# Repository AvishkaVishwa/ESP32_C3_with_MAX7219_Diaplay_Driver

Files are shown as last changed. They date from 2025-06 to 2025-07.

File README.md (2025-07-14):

# ⏰ ESP32‑Powered Smart Clock

> Elegant Wi‑Fi digital clock with MAX7219 4‑digit display, buzzer alarm, and full web control. 

>This project is a Wi-Fi-enabled digital clock built around an ESP32 module that drives a four-digit MAX7219 7-segment display to show real-time hours, minutes, and seconds. A responsive web interface served by the microcontroller lets you set the time, alarms, countdowns, timezone, and home-network credentials, while a buzzer and physical button provide audible alerts and quick dismissal. Running in dual AP/STA mode, the clock creates its own setup hotspot, reconnects to your home Wi-Fi for hourly SNTP synchronization, and stores all settings in NVS for stand-alone, always-accurate operation.
>I did this project to Improve my skills and knowledge in PCB designing and IOT developments.

<p align="center">
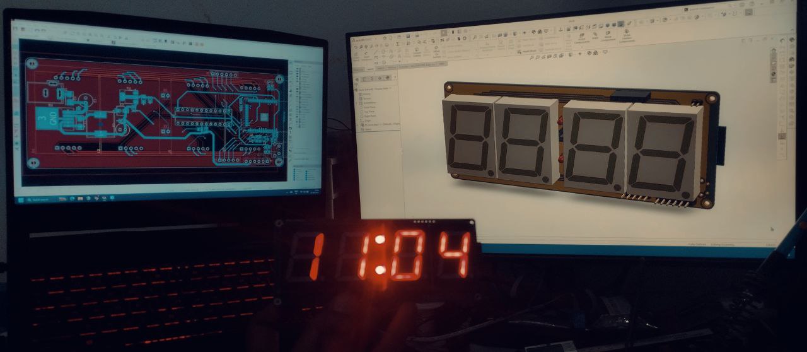
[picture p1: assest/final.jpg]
Clock demo
  
</p>

---

## ✨ Highlights

| | |
| --- | --- |
| **Real‑time display** | Bright 4‑digit 7‑segment driven by MAX7219 (HH\:MM\:SS) |
| **Responsive web UI** | Set time, alarms, countdown & Wi‑Fi from any browser |
| **Buzzer & button** | Loud alarm + physical dismiss (GPIO 0) |
| **Dual‑mode Wi‑Fi** | AP for local control (`Clock` SSID) + STA for internet time sync |
| **SNTP auto‑sync** | Keeps time accurate to seconds with pool.ntp.org |
| **Open hardware** | KiCad project, 3‑D renders, and BOM included |

---

## 🖼️ Gallery

Prototype🙌 
-For the Prototype I used a ESP32 C3 Super Mini Board 

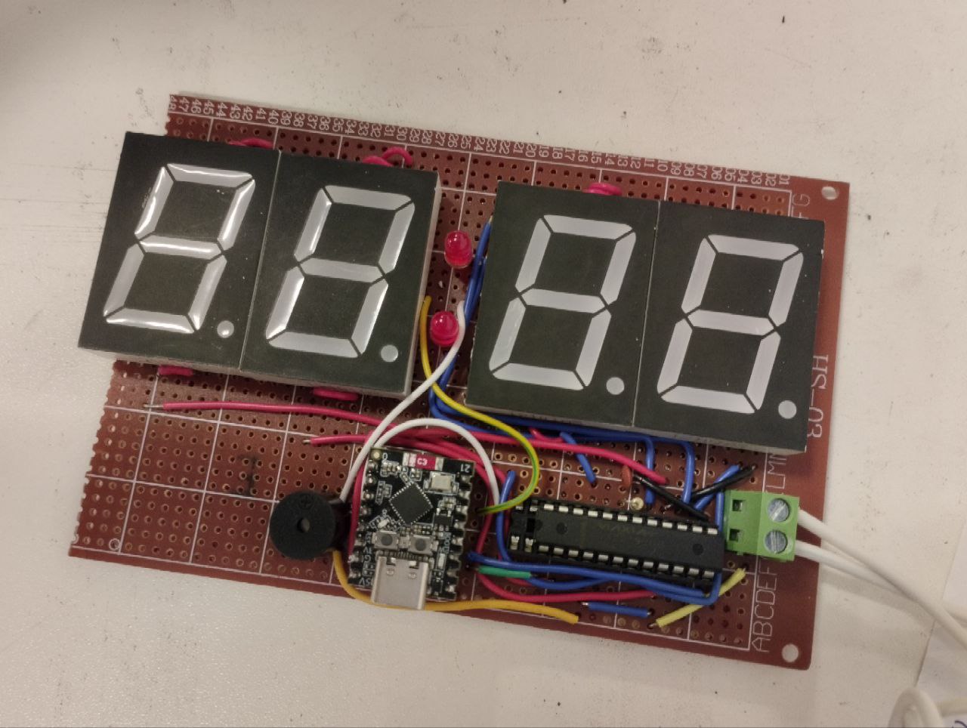
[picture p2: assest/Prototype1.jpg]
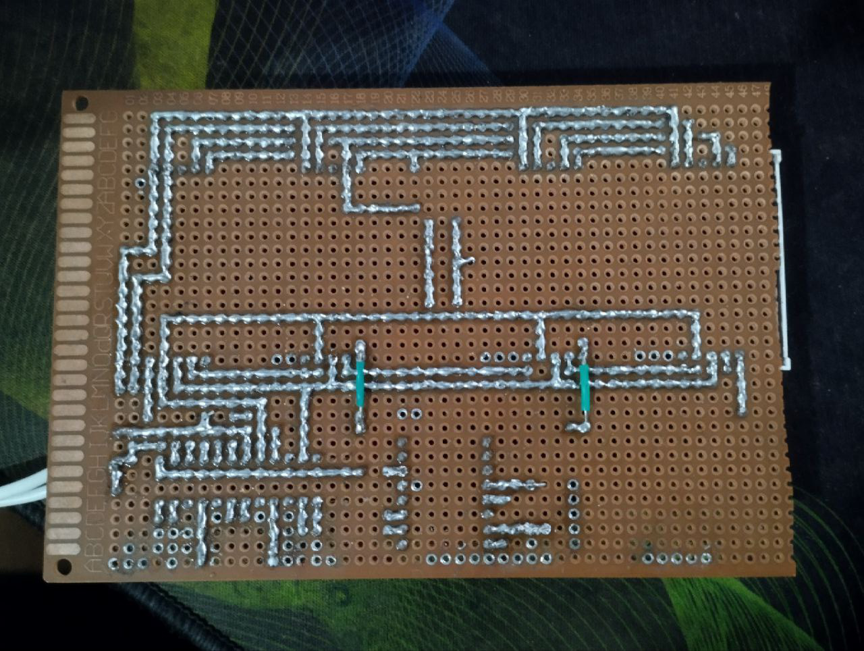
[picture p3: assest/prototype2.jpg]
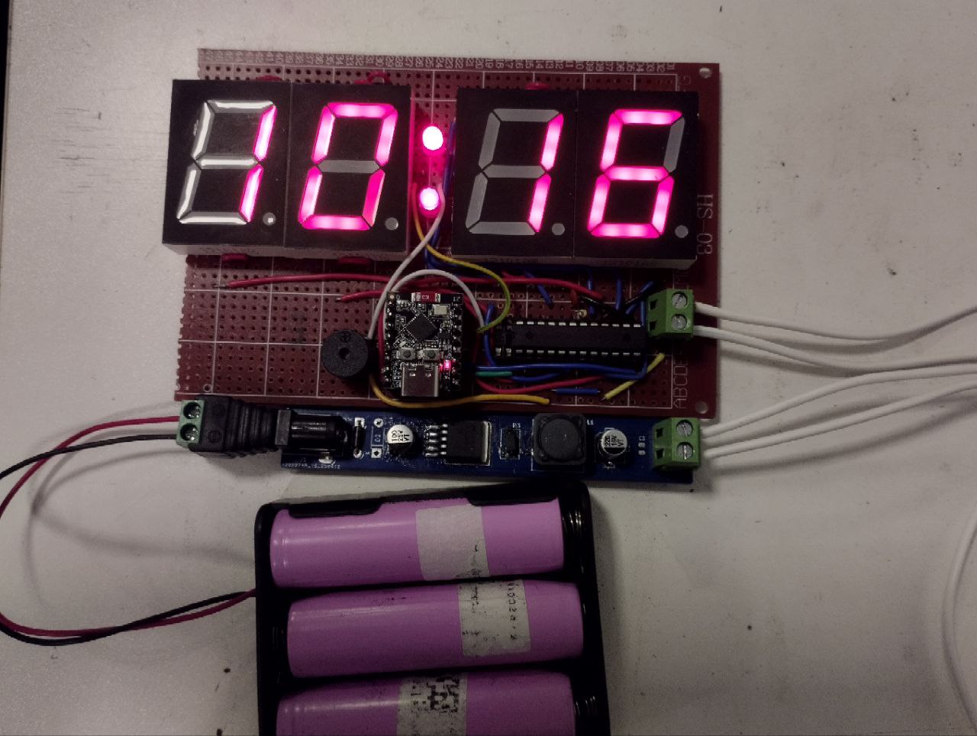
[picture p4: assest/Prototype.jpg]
      

| Web UI | PCB 3‑D | Copper |
| --- | --- | --- |
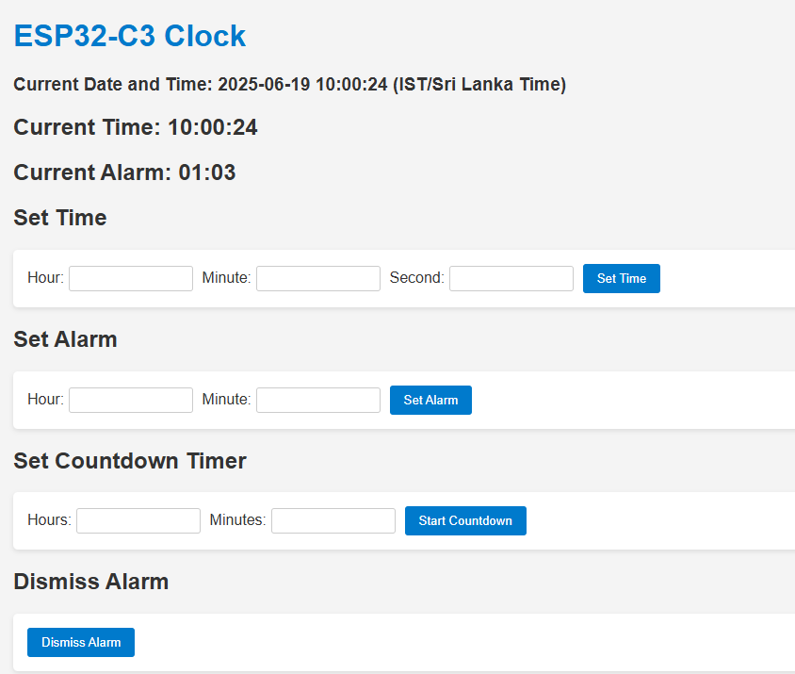
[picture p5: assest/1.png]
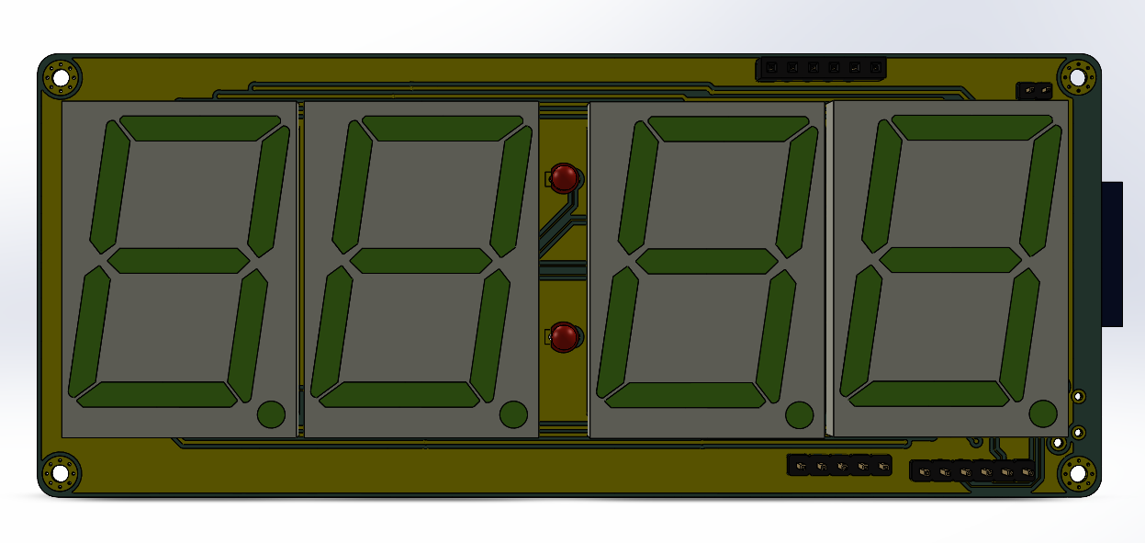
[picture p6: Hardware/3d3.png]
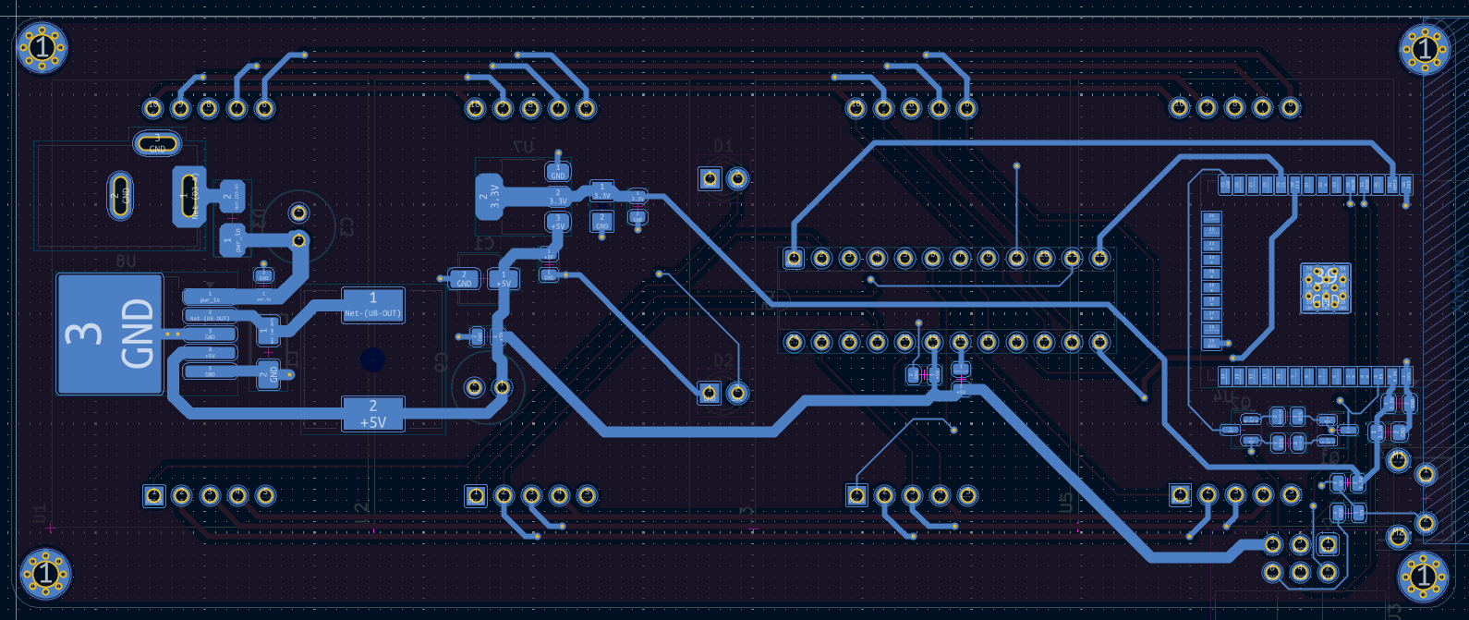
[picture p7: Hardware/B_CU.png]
|  |  |  |
                                                                                      
More in [**/assets**](assets) & [**/hardware**](hardware).

<video src ="https://github.com/user-attachments/assets/0d8d9107-081a-4ae7-bd47-be3cfd9f0423"></video>

So when we turned on the clock it takes 10 seconds to connect to the home wifi and connect to the NTP server update the time..

<video src ="https://github.com/user-attachments/assets/e7d40686-c1fc-4405-965b-9b872882c82c"></video>

---

## 🔌 Hardware List

| Qty | Part | Notes |
| --- | --- | --- |
| 1 | **ESP32‑WROOM‑32D** module | 38‑pin, 4 MB flash |
| 1 | **MAX7219** 8‑digit driver | Only digits 0‑3 used |
| 6 | 1.25" 7‑segment (common cathode) | HHMMSS |
| 1 | Piezo buzzer (3 V) | GPIO 4 |
| 1 | Tact switch | Dismiss, GPIO 0 |
| 2 | LEDs + 1 kΩ | Seconds (G2), AM/PM (G19)  |
| 1 | **LM2596S‑5.0** buck | 12 V → 5 V, feeds 3 V3 LDO |
| assorted | passives, headers | See schematic |

Schematic & PCB files: **`hardware/`** (KiCad 9).

---

## 🗺️ Wiring / Pin Map

```text
ESP32‑WROOM‑32D     MAX7219 / IO       Notes
─────────────────────────────────────────────────
GPIO23  ─────────── DIN      (SPI MOSI)
GPIO18  ─────────── CLK      (SPI SCK)
GPIO5   ─────────── CS       (SPI SS)
GPIO4   ─────────── Buzzer   Active‑high
GPIO0   ─────────── Button   Pulled‑up, boot mode when held
GPIO2   ─────────── Seconds‑LED
GPIO19  ─────────── AM/PM‑LED
3V3/5V  ─────────── VCC      MAX7219 tolerant
GND     ─────────── GND
```

---

## 🚀 Quick Start (Firmware)

```bash
# 1 · Clone and select target
$ git clone https://github.com/AvishkaVishwa/esp32-c3-clock.git
$ cd esp32-c3-clock/firmware
$ idf.py set-target esp32

# 2 · Install submodules & configure
$ git submodule update --init
$ idf.py menuconfig   # Wi‑Fi, timezone, pins, etc.

# 3 · Build, flash & monitor
$ idf.py build flash monitor
```

First boot ➡ creates open AP `Clock` (pwd **clockpass**). Browse to **[http://192.168.4.1](http://192.168.4.1)** to set local time & Wi‑Fi.

> **Tip:** Once connected to your home network the clock pulls NTP every hour.

---

## 🔧 Advanced Options

| Menu | Default | Description |
| --- | --- | --- |
| `Clock ▸ Timezone` | Asia/Colombo (+5:30) | Any UTC offset, 30 min granularity |
| `Clock ▸ Alarms ▸ Alarm 1` | 07:00 | Daily repeat |
| `Clock ▸ Wi‑Fi ▸ AP SSID` | Clock | Rename if multiple clocks |
| `Component ▸ HTTP Server ▸ Max URI handlers` | 15 | Reduce to save RAM |

---

## 🎉 Special Thanks to PCBWay

<div align="center">
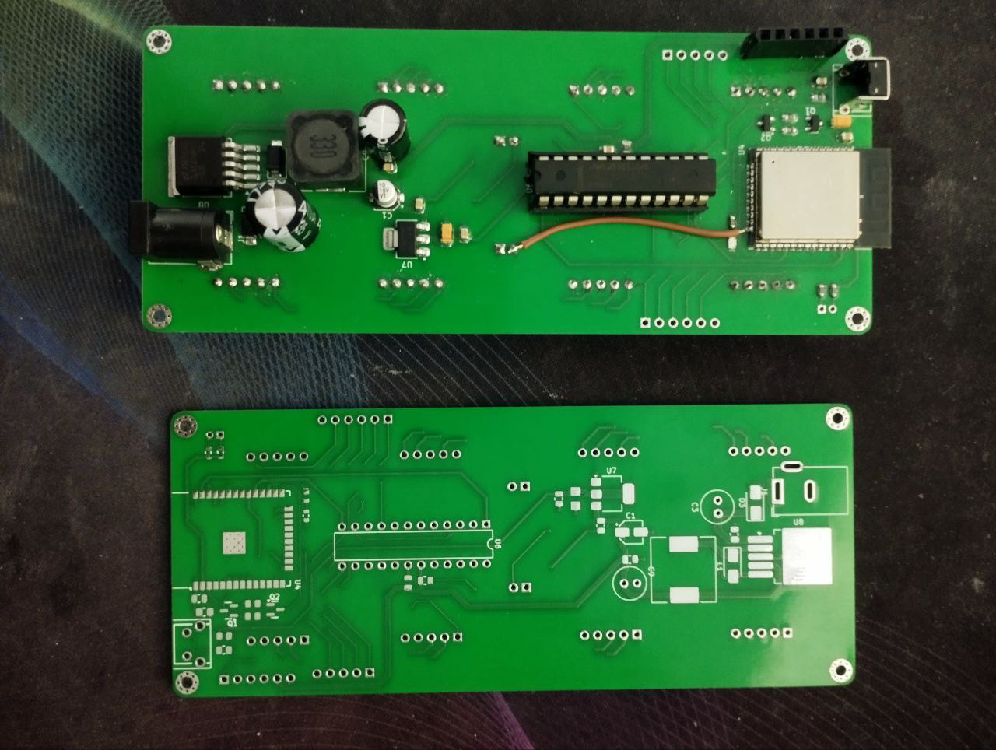
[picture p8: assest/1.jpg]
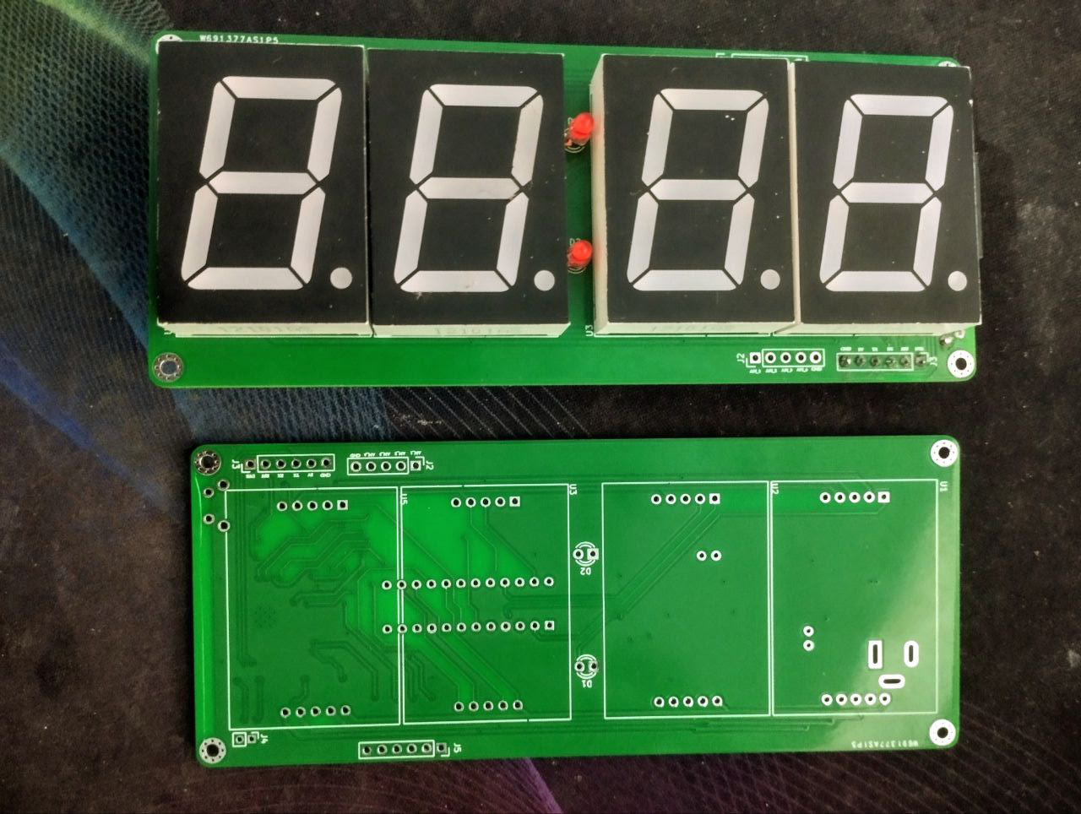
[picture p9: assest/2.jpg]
      
</div>

<p align="center">
  <a href="https://www.pcbway.com/" target="_blank">
    PCBWay
  </a>

</p>

I would like to give a huge shoutout and sincere thanks to **[PCBWay](https://www.pcbway.com/)** for sponsoring the PCB fabrication of this project!

The **build quality, silkscreen clarity, via precision, and copper finish** exceeded expectations. PCBWay’s service was fast, professional, and extremely helpful throughout the production process.

This project wouldn’t have been possible without their generous support. If you’re looking to manufacture professional-grade PCBs at an affordable price, I highly recommend checking them out.

🔗 [Visit PCBWay →](https://www.pcbway.com/)

---

---

> © 2025 Avishka Vishwa   •   Made with ☕ & 🕑

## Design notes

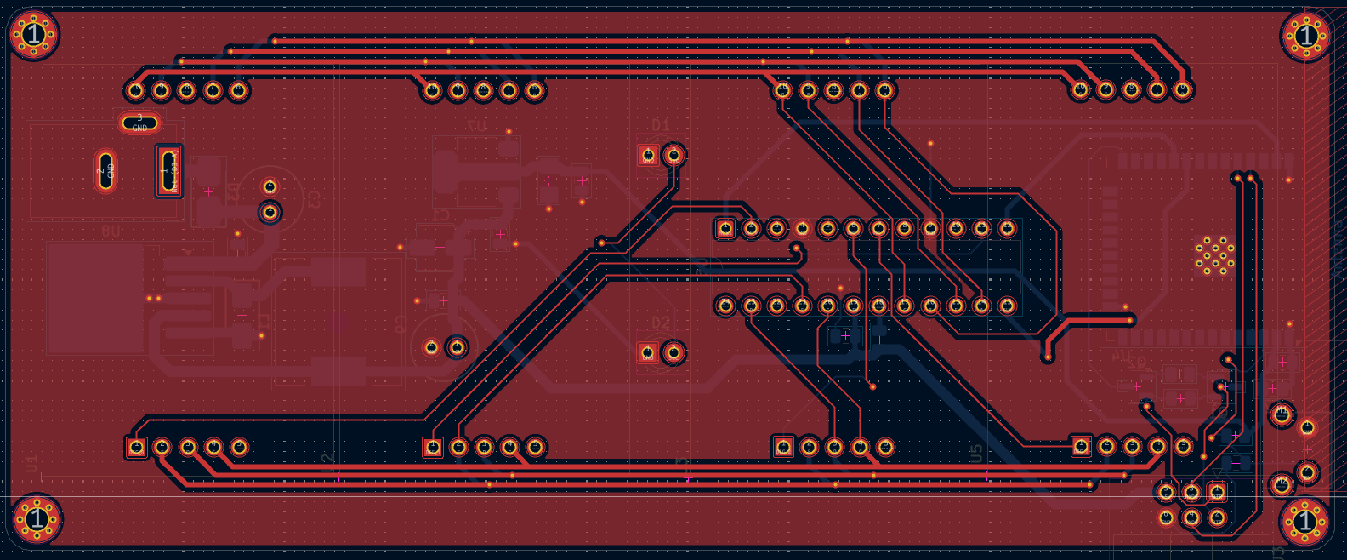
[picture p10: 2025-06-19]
Hardware/zone.png

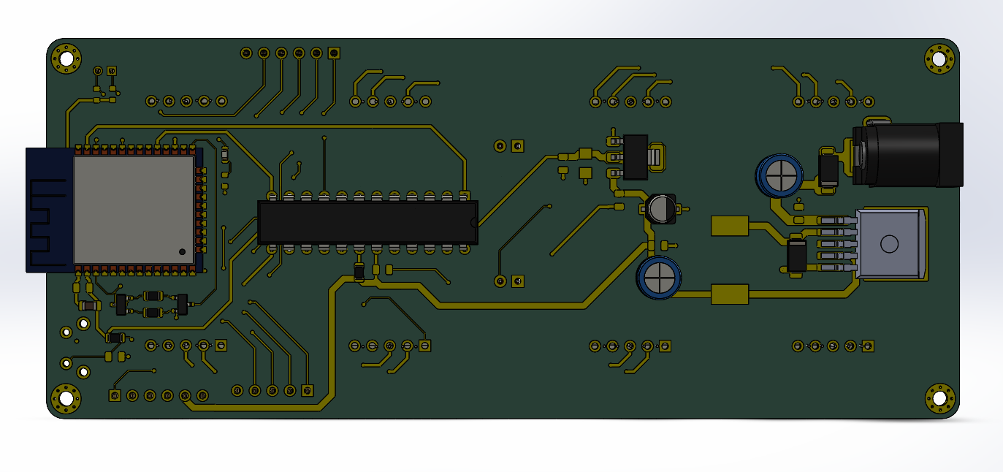
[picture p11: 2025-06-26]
Hardware/3d4.png

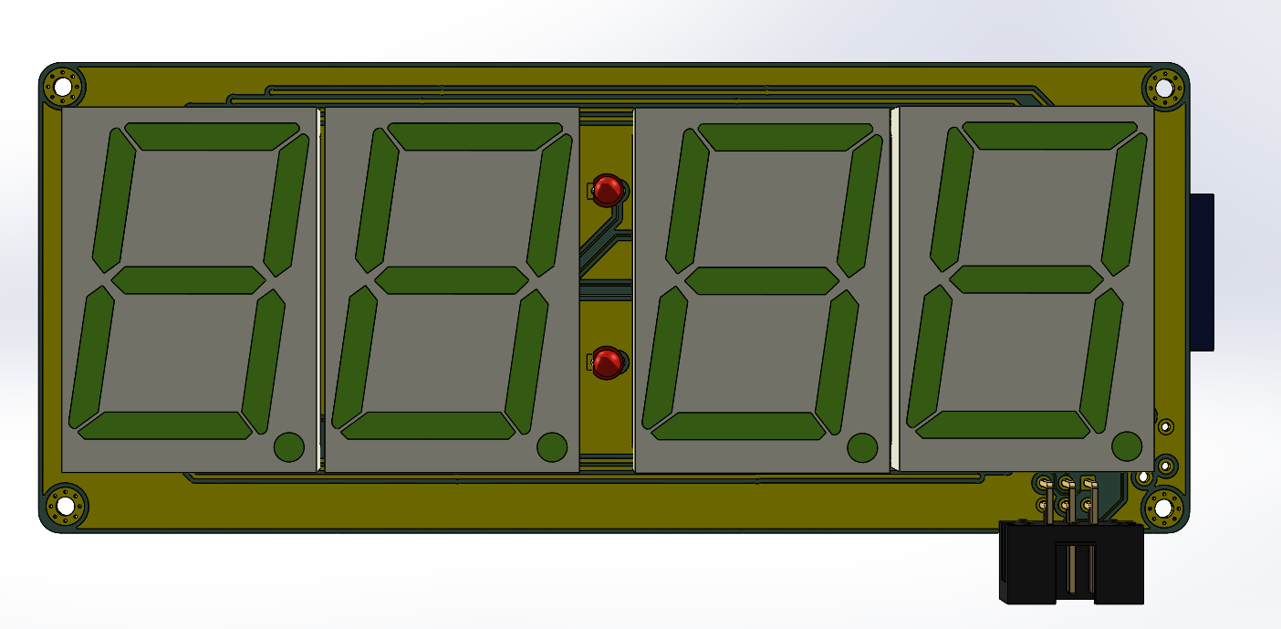
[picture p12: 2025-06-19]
Hardware/3d2.png

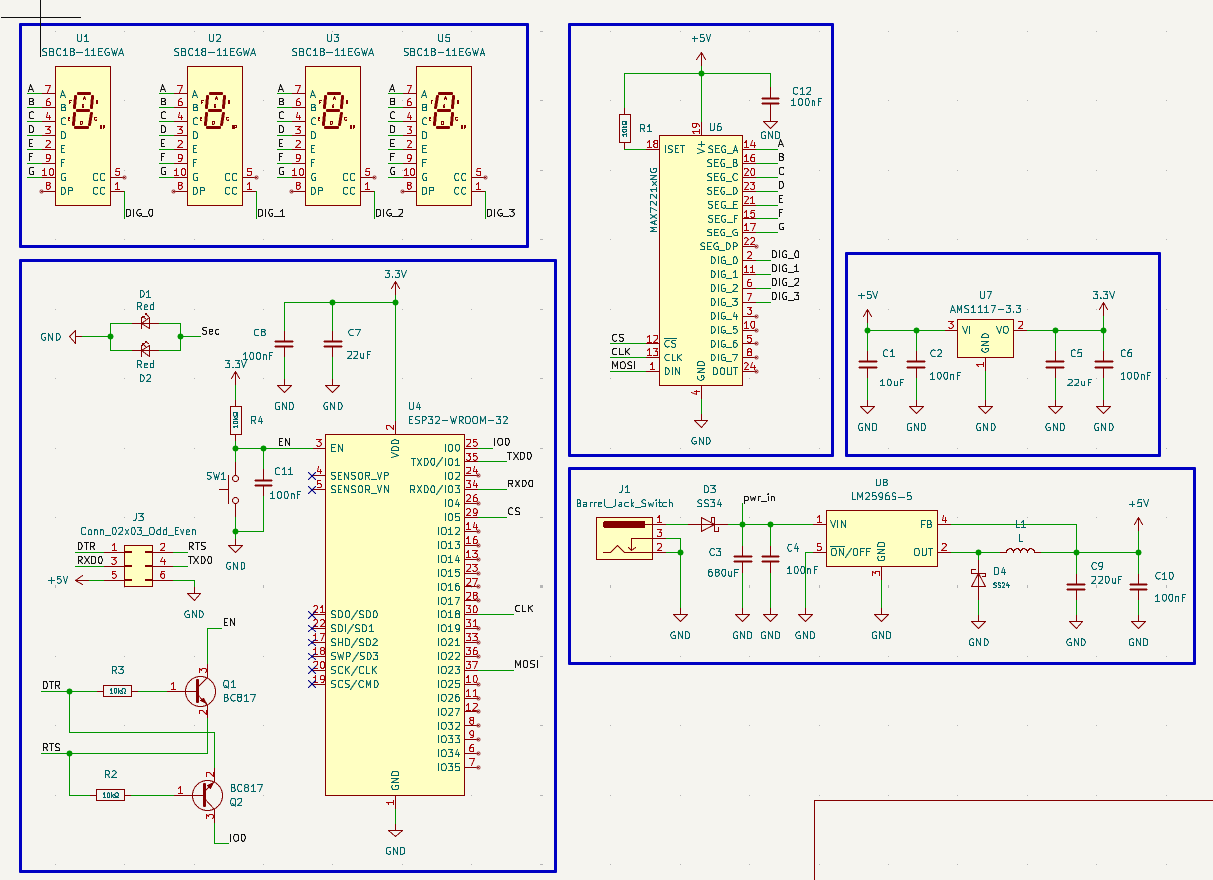
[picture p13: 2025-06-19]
Hardware/schimatic.png

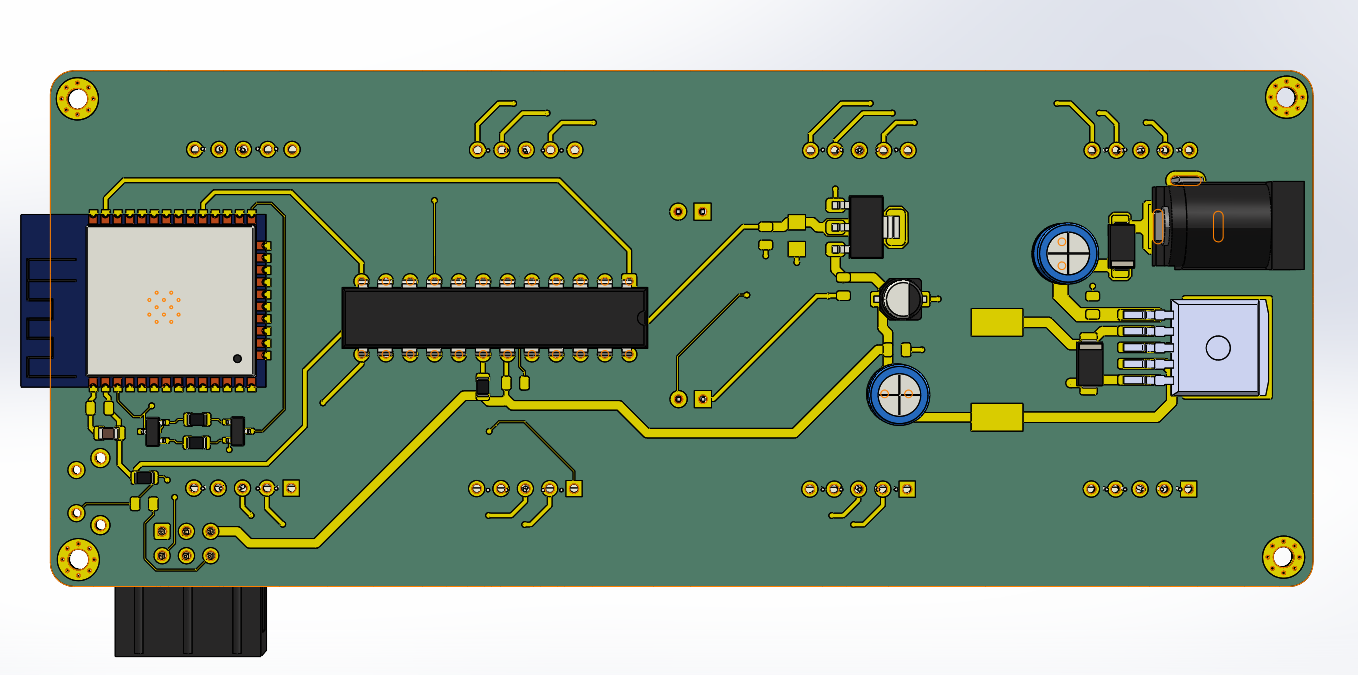
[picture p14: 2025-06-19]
Hardware/3d.png

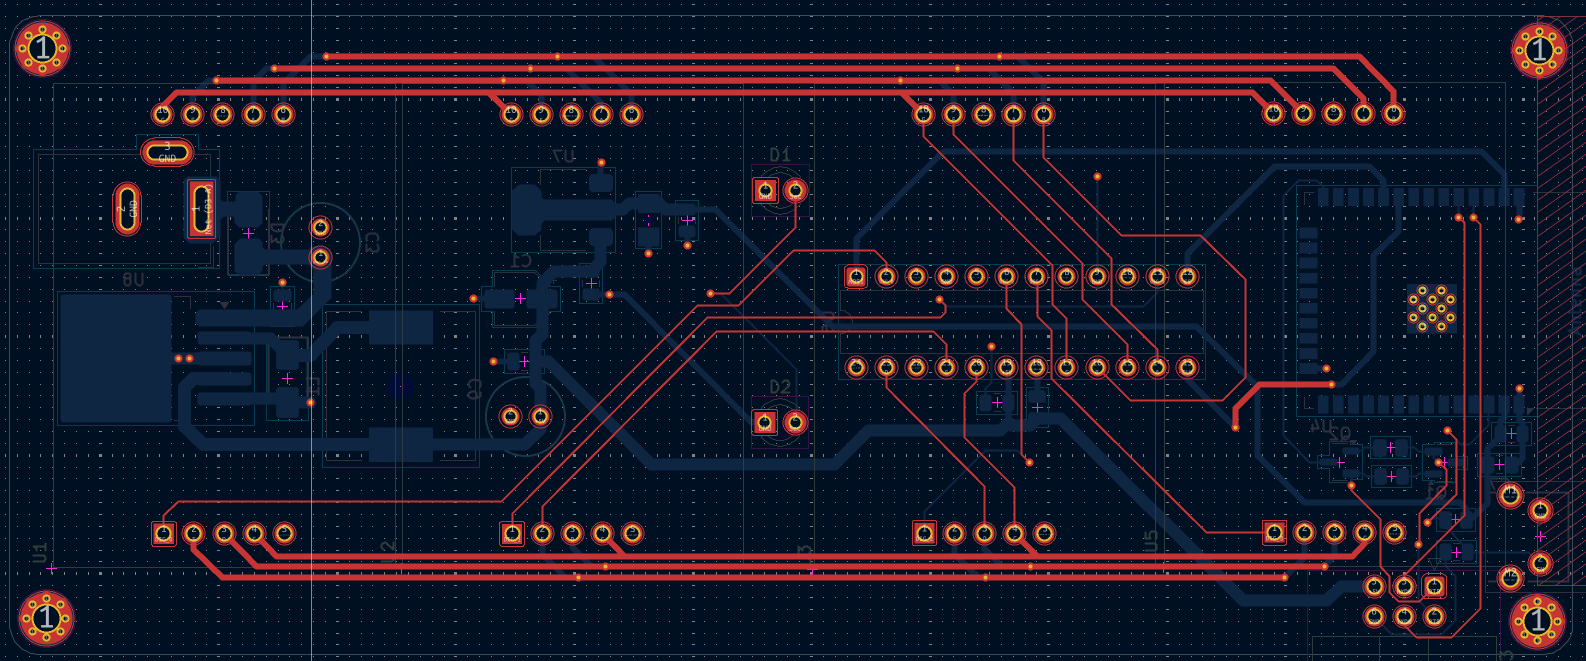
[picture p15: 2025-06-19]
Hardware/F_Cu.png

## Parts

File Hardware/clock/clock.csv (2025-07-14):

Id | Designator | Footprint | Quantity | Designation | Supplier and ref
1 | J4 | PinHeader_1x02_P2.00mm_Vertical | 1 | Conn_01x02_Pin
2 | J2 | PinHeader_1x05_P2.54mm_Vertical | 1 | Conn_01x05_Pin
3 | U5,U1,U2,U3 | SBC18-11SURKCGKWA | 4 | SBC18-11EGWA
4 | J5 | PinSocket_1x06_P2.54mm_Vertical | 1 | Conn_01x06_Pin
5 | D2,D1 | LED_D3.0mm | 2 | Red
6 | J3 | PinHeader_1x06_P2.54mm_Vertical | 1 | Conn_02x03_Odd_Even
7 | C1 | CP_Elec_4x5.4 | 1 | 10uF
8 | R7,R6 | R_0603_1608Metric | 2 | 4.7k
9 | C12,C8,C2,C11,C4,C10,C6 | C_0805_2012Metric | 7 | 100nF
10 | C5 | 1206 | 1 | 22uF
11 | U4 | ESP32-WROOM-32 | 1 | ESP32-WROOM-32
12 | SW1 | Push_PTH_RA_8-020_h7.5mm | 1 | PTH_RA_h7.5mm
13 | U7 | SOT-223-3_TabPin2 | 1 | AMS1117-3.3
14 | R3,R2,R1,R4 | R_0805 | 4 | 10kΩ
15 | U6 | DIP-24_W7.62mm | 1 | MAX7221xNG
16 | C3 | C_Radial_D6.3mm_H7.0mm_P2.50mm | 1 | 680uF
17 | U8 | TO-263-5_TabPin3 | 1 | LM2596S-5
18 | J1 | BarrelJack_GCT_DCJ200-10-A_Horizontal | 1 | Barrel_Jack_Switch
19 | C9 | C_Radial_D6.3mm_H5.0mm_P2.50mm | 1 | 220uF
20 | C7 | C_0805_2012Metric_Pad1.18x1.45mm_HandSolder | 1 | 22uF
21 | D5 | LED_0603_1608Metric | 1 | LED
22 | D3 | D_SMA | 1 | SS34
23 | D4 | D_SMA | 1 | SS24
24 | L1 | L_12x12mm_H8mm | 1 | L
25 | Q1,Q2 | SOT-23 | 2 | BC817
26 | R5 | R_0603_1608Metric | 1 | 1.5k

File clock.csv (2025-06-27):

Reference | Qty | Value | DNP | Exclude from BOM | Exclude from Board | Footprint | Datasheet
C1 | 1 | 10uF |  |  |  | Capacitor_SMD:CP_Elec_4x5.4 | https://cdn.sparkfun.com/assets/8/a/4/a/5/Kemet_Capacitor_Datasheet.pdf
C2,C4,C6,C8,C10,C11,C12 | 7 | 100nF |  |  |  | SparkFun-Capacitor:C_0805_2012Metric | https://cdn.sparkfun.com/assets/8/a/4/a/5/Kemet_Capacitor_Datasheet.pdf
C3 | 1 | 680uF |  |  |  | Capacitor_THT:C_Radial_D6.3mm_H7.0mm_P2.50mm | https://cdn.sparkfun.com/assets/8/a/4/a/5/Kemet_Capacitor_Datasheet.pdf
C5 | 1 | 22uF |  |  |  | SparkFun-Fuse:1206 | https://cdn.sparkfun.com/assets/8/a/4/a/5/Kemet_Capacitor_Datasheet.pdf
C7 | 1 | 22uF |  |  |  | Capacitor_SMD:C_0805_2012Metric_Pad1.18x1.45mm_HandSolder | https://cdn.sparkfun.com/assets/8/a/4/a/5/Kemet_Capacitor_Datasheet.pdf
C9 | 1 | 220uF |  |  |  | Capacitor_THT:C_Radial_D6.3mm_H5.0mm_P2.50mm | https://cdn.sparkfun.com/assets/8/a/4/a/5/Kemet_Capacitor_Datasheet.pdf
D1,D2 | 2 | Red |  |  |  | LED_THT:LED_D3.0mm | https://docs.broadcom.com/docs/AV02-0551EN
D3 | 1 | SS34 |  |  |  | Diode_SMD:D_SMA | https://www.vishay.com/docs/88751/ss32.pdf
D4 | 1 | SS24 |  |  |  | PCM_JLCPCB:D_SMA | https://wmsc.lcsc.com/wmsc/upload/file/pdf/v2/lcsc/2401290920_hongjiacheng-SS24_C7420362.pdf
D5 | 1 | LED |  |  |  | SparkFun-LED:LED_0603_1608Metric | ~
J1 | 1 | Barrel_Jack_Switch |  |  |  | Connector_BarrelJack:BarrelJack_GCT_DCJ200-10-A_Horizontal | ~
J2 | 1 | Conn_01x05_Pin |  |  |  | Connector_PinHeader_2.54mm:PinHeader_1x05_P2.54mm_Vertical | ~
J3 | 1 | Conn_02x03_Odd_Even |  |  |  | Connector_PinHeader_2.54mm:PinHeader_1x06_P2.54mm_Vertical | ~
J4 | 1 | Conn_01x02_Pin |  |  |  | Connector_PinHeader_2.00mm:PinHeader_1x02_P2.00mm_Vertical | ~
J5 | 1 | Conn_01x06_Pin |  |  |  | Connector_PinSocket_2.54mm:PinSocket_1x06_P2.54mm_Vertical | ~
L1 | 1 | L |  |  |  | Inductor_SMD:L_12x12mm_H8mm | ~
Q1,Q2 | 2 | BC817 |  |  |  | Package_TO_SOT_SMD:SOT-23 | https://www.onsemi.com/pub/Collateral/BC818-D.pdf
R1,R2,R3,R4 | 4 | 10kΩ |  |  |  | PCM_JLCPCB:R_0805 | https://www.lcsc.com/datasheet/lcsc_datasheet_2411221126_UNI-ROYAL-Uniroyal-Elec-0805W8F1002T5E_C17414.pdf
R5 | 1 | 1.5k |  |  |  | SparkFun-Resistor:R_0603_1608Metric | https://www.vishay.com/docs/20035/dcrcwe3.pdf
R6,R7 | 2 | 4.7k |  |  |  | SparkFun-Resistor:R_0603_1608Metric | https://www.vishay.com/docs/20035/dcrcwe3.pdf
SW1 | 1 | PTH_RA_h7.5mm |  |  |  | SparkFun-Switch:Push_PTH_RA_8-020_h7.5mm | ~
U1,U2,U3,U5 | 4 | SBC18-11EGWA |  |  |  | Display_7Segment:SBC18-11SURKCGKWA | http://www.kingbrightusa.com/images/catalog/SPEC/SBC18-11EGWA.pdf
U4 | 1 | ESP32-WROOM-32 |  |  |  | RF_Module:ESP32-WROOM-32 | https://www.espressif.com/sites/default/files/documentation/esp32-wroom-32_datasheet_en.pdf
U6 | 1 | MAX7221xNG |  |  |  | Package_DIP:DIP-24_W7.62mm | https://datasheets.maximintegrated.com/en/ds/MAX7219-MAX7221.pdf
U7 | 1 | AMS1117-3.3 |  |  |  | Package_TO_SOT_SMD:SOT-223-3_TabPin2 | http://www.advanced-monolithic.com/pdf/ds1117.pdf
U8 | 1 | LM2596S-5 |  |  |  | Package_TO_SOT_SMD:TO-263-5_TabPin3 | http://www.ti.com/lit/ds/symlink/lm2596.pdf

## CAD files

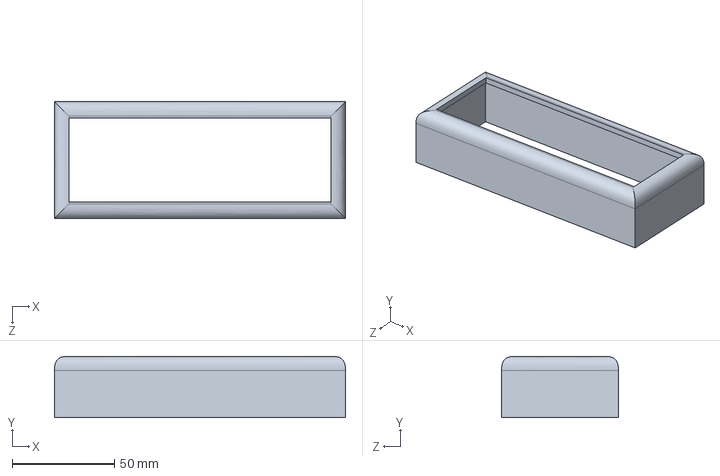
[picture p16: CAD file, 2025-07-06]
Hardware/clock3d/clock/Assem7.SLDASM
142.0 x 30.0 x 57.0 mm

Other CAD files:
Hardware/clock3d/clock/Part1.SLDPRT

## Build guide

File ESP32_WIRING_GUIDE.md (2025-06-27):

# ESP32 WROOM-32D Clock Wiring Guide

## Component Connections

### MAX7219 7-Segment Display Module
```
MAX7219 Pin  →  ESP32 Pin
VCC          →  3.3V or 5V (depending on your module)
GND          →  GND
DIN (Data)   →  GPIO23 (MOSI)
CS (Load)    →  GPIO5
CLK (Clock)  →  GPIO18 (SCK)
```

### Buzzer (Active or Passive)
```
Buzzer Pin   →  ESP32 Pin
VCC/+        →  GPIO4
GND/-        →  GND
```

### LEDs
```
Component       →  ESP32 Pin
Seconds LED     →  GPIO2 (built-in LED on most boards)
AM/PM LED       →  GPIO19 → LED → 220Ω resistor → GND
```

### Button (Optional - GPIO0 BOOT button can be used)
```
External Button →  ESP32 Pin
One terminal    →  GPIO0 (or use built-in BOOT button)
Other terminal  →  GND
```

## Power Supply
- ESP32 WROOM-32D: 3.3V (regulated internally from 5V USB or Vin)
- MAX7219: Can work with 3.3V or 5V (check your module specifications)
- Total current: ~200-500mA depending on display brightness

## Important Notes

### GPIO Constraints for ESP32 WROOM-32D:
- **GPIO0**: Boot button (pulled up, goes LOW when pressed)
- **GPIO2**: Built-in LED on many boards, can be used as output
- **GPIO6-11**: Connected to flash memory - DO NOT USE
- **GPIO12**: Boot configuration pin - avoid if possible
- **GPIO15**: Boot configuration pin - avoid if possible

### Safe GPIO pins for ESP32 WROOM-32D:
- **Input/Output**: 4, 5, 16, 17, 18, 19, 21, 22, 23, 25, 26, 27, 32, 33
- **Input Only**: 34, 35, 36, 39 (no internal pull-up)

### SPI Pins (HSPI):
- **MOSI**: GPIO23
- **MISO**: GPIO19 (not used in this project)
- **SCK**: GPIO18
- **CS**: Any GPIO (we use GPIO5)

## Testing Steps

1. **Power on ESP32** - Check if built-in LED blinks
2. **Connect Serial Monitor** - Look for boot messages
3. **Test Display** - Should see segment test pattern on startup
4. **Test WiFi** - Look for "Clock" WiFi network
5. **Test Web Interface** - Connect to 192.168.4.1
6. **Test Hardware** - Check buttons, LEDs, buzzer, display

## Troubleshooting

### Display not working:
- Check 3.3V vs 5V requirements of your MAX7219 module
- Verify SPI connections (DIN=GPIO23, CLK=GPIO18, CS=GPIO5)
- Try lower SPI clock speed (already set to 5MHz)
- Check GND connection

### WiFi issues:
- Look for "Clock" network with password "clockpass"
- Check serial output for connection messages
- Try factory reset (hold GPIO0 while powering on)

### Button not responding:
- GPIO0 (BOOT button) should work immediately
- External button needs debouncing (already implemented)
- Check GND connection for external buttons

### Buzzer silent:
- Check if it's active or passive buzzer
- Active buzzer: Just needs DC voltage
- Passive buzzer: Needs square wave (current code works for both)
- Check GPIO4 connection

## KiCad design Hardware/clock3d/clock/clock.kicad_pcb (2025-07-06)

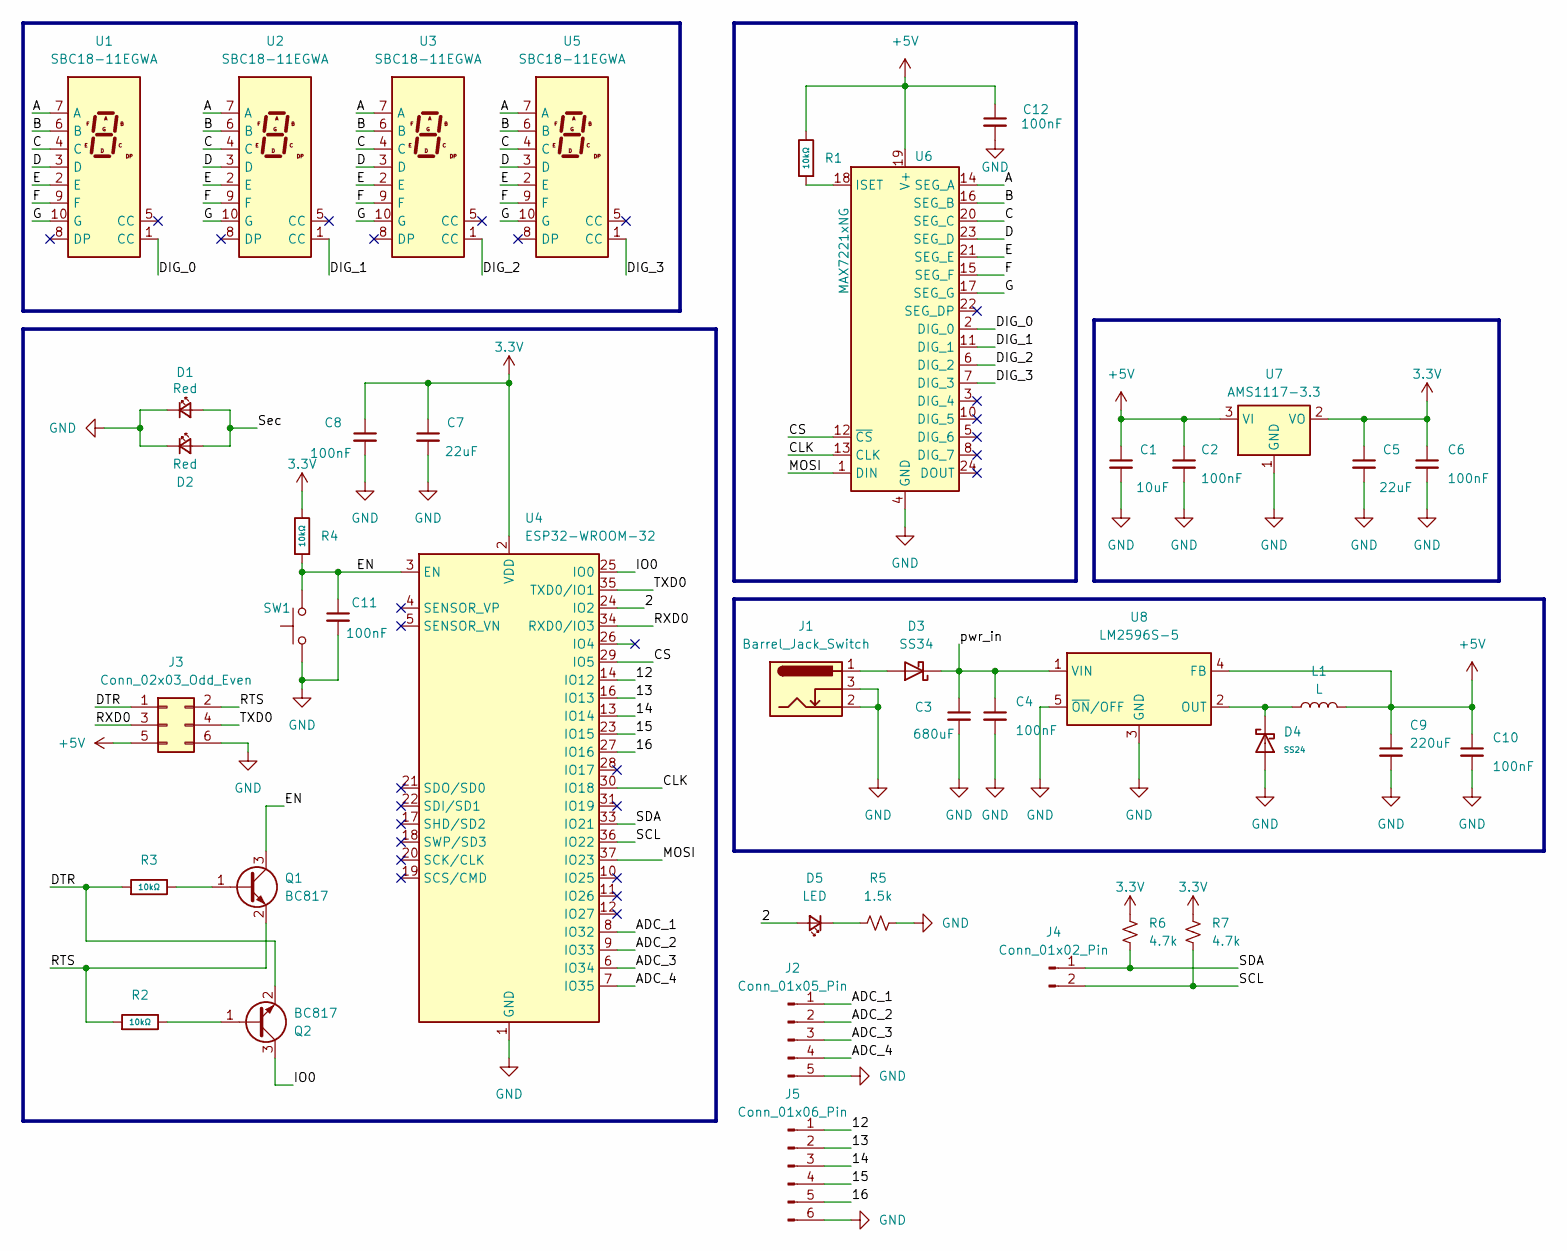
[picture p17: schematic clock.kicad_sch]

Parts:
C1: 10uF; CP_Elec_4x5.4; Voltage 1kV; Tolerance 100%
C2, C4, C6, C8, C10, C11, C12: 100nF; C_0805_2012Metric; Voltage 1kV; Tolerance 100%
C3: 680uF; C_Radial_D6.3mm_H7.0mm_P2.50mm; Voltage 1kV; Tolerance 100%
C5: 22uF; 1206; Voltage 1kV; Tolerance 100%
C7: 22uF; C_0805_2012Metric_Pad1.18x1.45mm_HandSolder; Voltage 1kV; Tolerance 100%
C9: 220uF; C_Radial_D6.3mm_H5.0mm_P2.50mm; Voltage 1kV; Tolerance 100%
D1, D2: Red; LED_D3.0mm
D3: SS34; D_SMA
D4: SS24; D_SMA; Forward Voltage (Vf@If) 0.55V@1.0A; Reverse Voltage (Vr) 40V; Part SS24; LCSC C7420362
D5: LED; LED_0603_1608Metric
J1: Barrel_Jack_Switch; BarrelJack_GCT_DCJ200-10-A_Horizontal
J2: Conn_01x05_Pin; PinHeader_1x05_P2.54mm_Vertical
J3: Conn_02x03_Odd_Even; PinHeader_1x06_P2.54mm_Vertical
J4: Conn_01x02_Pin; PinHeader_1x02_P2.00mm_Vertical
J5: Conn_01x06_Pin; PinSocket_1x06_P2.54mm_Vertical
L1: L; L_12x12mm_H8mm
Q1, Q2: BC817; SOT-23
R1, R2, R3, R4: 10kΩ; R_0805; Overload Voltage (Max) 150V; Tolerance ±1%; Part 0805W8F1002T5E; LCSC C17414
R5: 1.5k; R_0603_1608Metric
R6, R7: 4.7k; R_0603_1608Metric
SW1: PTH_RA_h7.5mm; Push_PTH_RA_8-020_h7.5mm; Mfg Part# 8-020 TS H = 7.5mm
U1, U2, U3, U5: SBC18-11EGWA; SBC18-11SURKCGKWA
U4: ESP32-WROOM-32
U6: MAX7221xNG; DIP-24_W7.62mm
U7: AMS1117-3.3; SOT-223-3_TabPin2
U8: LM2596S-5; TO-263-5_TabPin3

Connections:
3.3V: C5.1, C6.1, C7.1, C8.1, R4.2, R6.2, R7.2, U4.2 (VDD), U7.2 (VO)
+5V: C1.1, C2.1, C9.1, C10.1, C12.1, J3.5, L1.2, R1.2, U6.19 (V+), U7.3 (VI), U8.4 (FB)
/2: D5.2 (A), U4.24 (IO2)
/12: J5.1, U4.14 (IO12)
/13: J5.2, U4.16 (IO13)
/14: J5.3, U4.13 (IO14)
/15: J5.4, U4.23 (IO15)
/16: J5.5, U4.27 (IO16)
/A: U1.7 (A), U2.7 (A), U3.7 (A), U5.7 (A), U6.14 (SEG_A)
/ADC_1: J2.1, U4.8 (IO32)
/ADC_2: J2.2, U4.9 (IO33)
/ADC_3: J2.3, U4.6 (IO34)
/ADC_4: J2.4, U4.7 (IO35)
/B: U1.6 (B), U2.6 (B), U3.6 (B), U5.6 (B), U6.16 (SEG_B)
/C: U1.4 (C), U2.4 (C), U3.4 (C), U5.4 (C), U6.20 (SEG_C)
/CLK: U4.30 (IO18), U6.13 (CLK)
/CS: U4.29 (IO5), U6.12 (~CS)
/D: U1.3 (D), U2.3 (D), U3.3 (D), U5.3 (D), U6.23 (SEG_D)
/DIG_0: U1.1 (CC), U6.2 (DIG_0)
/DIG_1: U2.1 (CC), U6.11 (DIG_1)
/DIG_2: U3.1 (CC), U6.6 (DIG_2)
/DIG_3: U5.1 (CC), U6.7 (DIG_3)
/DTR: J3.1, Q2.2 (E), R3.1
/E: U1.2 (E), U2.2 (E), U3.2 (E), U5.2 (E), U6.21 (SEG_E)
/EN: C11.1, Q1.3 (C), R4.1, SW1.2, U4.3 (EN)
/F: U1.9 (F), U2.9 (F), U3.9 (F), U5.9 (F), U6.15 (SEG_F)
/G: U1.10 (G), U2.10 (G), U3.10 (G), U5.10 (G), U6.17 (SEG_G)
/IO0: Q2.3 (C), U4.25 (IO0)
/MOSI: U4.37 (IO23), U6.1 (DIN)
/RTS: J3.2, Q1.2 (E), R2.1
/RXD0: J3.3, U4.34 (RXD0/IO3)
/SCL: J4.2, R7.1, U4.36 (IO22)
/SDA: J4.1, R6.1, U4.33 (IO21)
/Sec: D1.2 (A), D2.2 (A)
/TXD0: J3.4, U4.35 (TXD0/IO1)
/pwr_in: C3.1, C4.1, D3.1 (K), U8.1 (VIN)
GND: C1.2, C2.2, C3.2, C4.2, C5.2, C6.2, C7.2, C8.2, C9.2, C10.2, C11.2, C12.2, D1.1 (K), D2.1 (K), D4.2, J1.2, J1.3, J2.5, J3.6, J5.6, R5.2, SW1.1, U4.1 (GND), U4.15 (GND), U4.38 (GND), U4.39 (GND), U6.4 (GND), U6.9 (GND), U7.1 (GND), U8.3 (GND), U8.5 (~ON/OFF)
unnamed: D3.2 (A), J1.1
unnamed: D5.1 (K), R5.1
unnamed: Q1.1 (B), R3.2
unnamed: Q2.1 (B), R2.2
unnamed: R1.1, U6.18 (ISET)
unnamed: D4.1, L1.1, U8.2 (OUT)

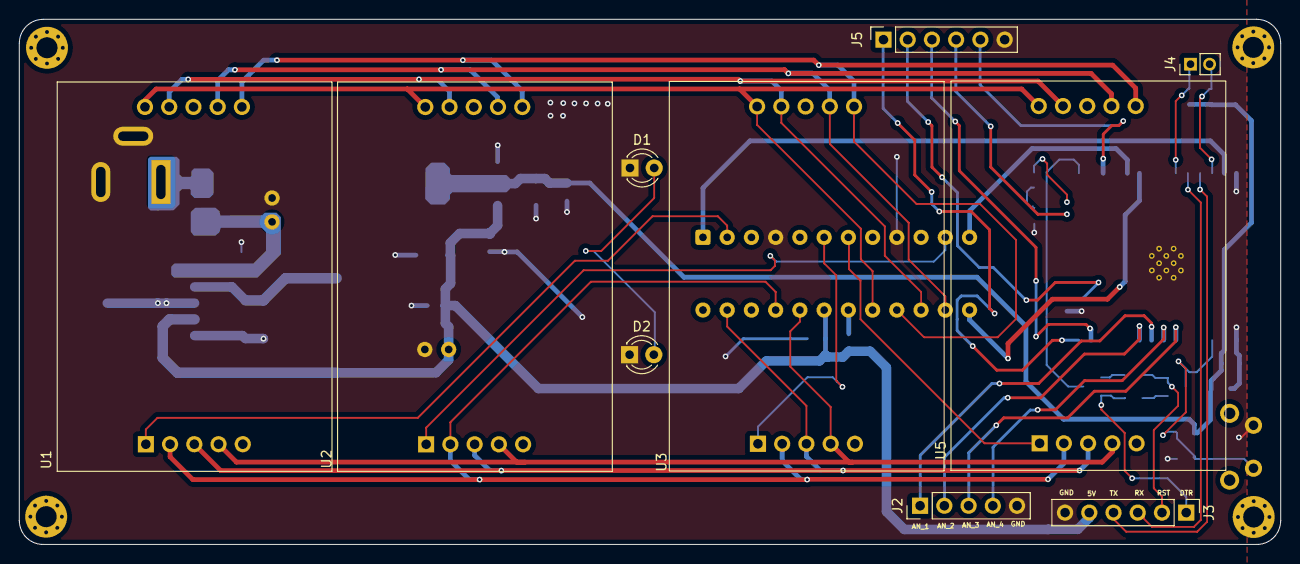
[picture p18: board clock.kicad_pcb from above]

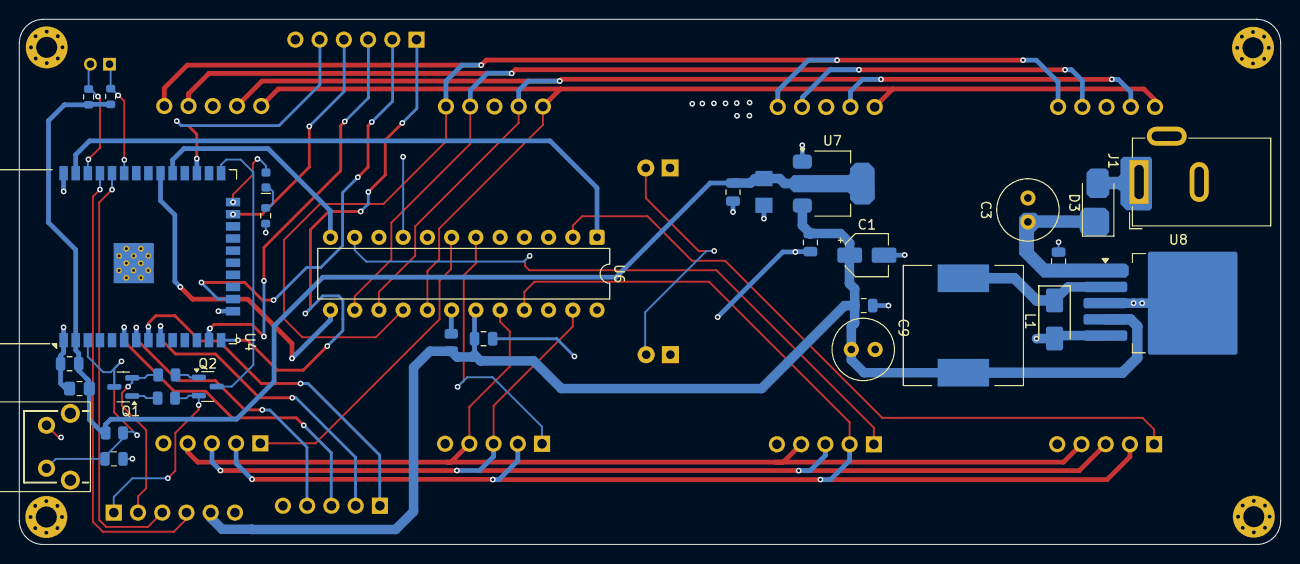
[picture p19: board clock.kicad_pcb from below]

Board: 2 copper layers, 132.2 x 55.0 mm, 41 parts (31 on the bottom side), 43 nets.

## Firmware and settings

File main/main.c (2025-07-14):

#include <stdio.h>
#include <string.h>
#include <time.h>
#include <sys/time.h>
#include "freertos/FreeRTOS.h"
#include "freertos/task.h"
#include "esp_log.h"
#include "nvs_flash.h"
#include "driver/gpio.h"

#include "app_config.h"
#include "display_manager.h"
#include "wifi_manager.h"
#include "time_utils.h"
#include "web_server.h"

extern struct tm current_time;
void app_main(void)
{
    // Initialize NVS
    esp_err_t ret = nvs_flash_init();
    if (ret == ESP_ERR_NVS_NO_FREE_PAGES || ret == ESP_ERR_NVS_NEW_VERSION_FOUND) {
        ESP_ERROR_CHECK(nvs_flash_erase());
        ret = nvs_flash_init();
    }
    ESP_ERROR_CHECK(ret);

    display_manager_init();
    display_message("INIT");
    vTaskDelay(1000 / portTICK_PERIOD_MS);
    display_clear();

    wifi_manager_init();

    if (wifi_manager_load_sta_config()) {
        if (wifi_manager_connect_to_ap() == ESP_OK) {
            // Connection successful, wifi_connected is set in the wifi_manager
        } else {
            // Connection failed, start AP mode
            display_message("FAIL");
            vTaskDelay(1000 / portTICK_PERIOD_MS);
            wifi_manager_start_ap();
            display_message("AP ON");
        }
    } else {
        // No STA config found, start AP mode
        wifi_manager_start_ap();
        display_message("AP ON");
    }

    web_server_start();

    if (wifi_connected) {
        sync_time();
    }

    while (1) {
        if (wifi_connected) {
            update_time();
            display_manager_show_time(current_time.tm_hour, current_time.tm_min, current_time.tm_sec);
        }
        vTaskDelay(1000 / portTICK_PERIOD_MS);
    }
}

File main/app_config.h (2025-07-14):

/*
 * app_config.h
 *
 *  Created on: Jul 9, 2025
 *      Author: GitHub Copilot
 */

#ifndef MAIN_APP_CONFIG_H_
#define MAIN_APP_CONFIG_H_

#include <stdio.h>
#include <string.h>
#include <time.h>
#include <sys/time.h>
#include "freertos/FreeRTOS.h"
#include "freertos/task.h"
#include "freertos/event_groups.h"
#include "esp_system.h"
#include "esp_log.h"
#include "esp_netif.h"
#include "esp_event.h"
#include "esp_wifi.h"
#include "nvs_flash.h"
#include "driver/gpio.h"
#include "driver/spi_master.h"
#include "lwip/err.h"
#include "lwip/sys.h"
#include "esp_http_server.h"
#include "esp_sntp.h"
#include "esp_timer.h"

// Pin definitions for ESP32 WROOM-32D
#define PIN_NUM_MOSI 23
#define PIN_NUM_CLK  18
#define PIN_NUM_CS   5
#define BUZZER_PIN   4
#define DISMISS_BUTTON_PIN 0 // GPIO0 is the BOOT button
#define SECONDS_LED_PIN 2
#define AMPM_LED_PIN 19

// Wi-Fi AP credentials
#define WIFI_AP_SSID "ESP32_Clock"
#define WIFI_AP_PASSWORD "12345678"

// Global variables (declared as extern)
extern spi_device_handle_t spi;
extern int alarm_hour;
extern int alarm_minute;
extern bool alarm_triggered;
extern int timezone_hours;
extern int timezone_minutes;
extern char wifi_ssid[32];
extern char wifi_password[64];
extern bool wifi_has_password;
extern bool wifi_sta_connected;
extern int ap_client_count;
extern bool reconnect_timer_active;
extern SemaphoreHandle_t wifi_semaphore;

#endif /* MAIN_APP_CONFIG_H_ */

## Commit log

2025-06-06 Update README.md to provide detailed project documentation for ESP32-C3 digital clock with web interface
2025-06-06 Update project title in README.md to include MAX7219 Display Driver
2025-06-16 Add lock file for clock schematic with hostname and username information
    [clock.kicad_pcb, clock.kicad_sch]
2025-06-17 Refactor code structure for improved readability and maintainability
    [clock-B_Cu.gbr, clock-B_Mask.gbr, clock-B_Paste.gbr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]
2025-06-19 Update README.md to correct image paths and enhance PCB design section
2025-06-19 Fix PCB render image path in README.md
2025-06-19 Add missing PCB render images to README.md
2025-06-26 Add initial PCB lock file and component list for clock project
    - Created a lock file for the PCB design with hostname and username.
    - Added a comprehensive CSV file listing components for the clock project, including values, footprints, and datasheets for each component.
    [clock-B_Cu.gbr, clock-B_Mask.gbr, clock-B_Paste.gbr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]
2025-06-26 Update ESP-IDF configurations to target esp32 and correct compiler path
2025-06-27 Add CHECKSUMS.json for zorxx__rtci2c component with file hashes and metadata
    [clock-B_Cu.gbr, clock-B_Mask.gbr, clock-B_Paste.gbr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]
2025-06-29 Update README.md to enhance gallery section and add special thanks to PCBWay for project sponsorship
2025-06-29 Add acknowledgment for PCBWay sponsorship in README.md
2025-06-29 Add initial clock component definitions to clock.csv
    [clock.csv]
2025-06-29 Remove NPTH and PTH drill files along with the associated job file for the clock project to streamline the design and eliminate unnecessary components.
    [clock-B_Cu.gbr, clock-B_Mask.gbr, clock-B_Paste.gbr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]
2025-06-29 Update README.md to include additional prototype images for better visualization
2025-06-29 Update README.md to correct MAX7219 driver digit usage from 0-5 to 0-3
2025-07-14 feat: Initial implementation of ESP32 Clock application
    - Added app_config.h for configuration constants and global variables.
    - Implemented display_manager for controlling MAX7219 display.
    - Created max7219 driver for handling display commands.
    - Developed time_utils for managing time synchronization and settings.
    - Established web_server for handling HTTP requests for clock settings.
    - Implemented wifi_manager for managing WiFi connections and configurations.
    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
    [Assem7.SLDASM, Part1.SLDPRT, clock.csv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]
